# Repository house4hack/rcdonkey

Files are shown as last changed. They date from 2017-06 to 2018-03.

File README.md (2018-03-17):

RC Donkey
====

Based on the excellent project by Will Roscoe [https://github.com/wroscoe/donkey]

Simplified to use RC during training and driving - removing the need for WiFi and control using smartphone.

Talk from SatRDay included as a branch.

To automate running donkeyreader:

```
---------------------------------------------------

pi@raspberrypi:~ $ cat /etc/init.d/run_ai.sh
#!/bin/bash
### BEGIN INIT INFO
# Provides:          sample.py
# Required-Start:    $remote_fs $syslog
# Required-Stop:     $remote_fs $syslog
# Default-Start:     2 3 4 5
# Default-Stop:      0 1 6
# Short-Description: Start daemon at boot time
# Description:       Enable service provided by daemon.
### END INIT INFO

cd /home/pi/rcdonkey/donkeyreader/
./run.sh
pi@raspberrypi:~ $

pi@raspberrypi:~ $ sudo chmod +x /etc/init.d/run_ai.sh
pi@raspberrypi:~ $ sudo update-rc.d run_ai.sh defaults
pi@raspberrypi:~ $ sudo reboot

Done, once your Raspi booted up run.sh (donkeyreader) should already run in the background
---------------------------------------------------
```

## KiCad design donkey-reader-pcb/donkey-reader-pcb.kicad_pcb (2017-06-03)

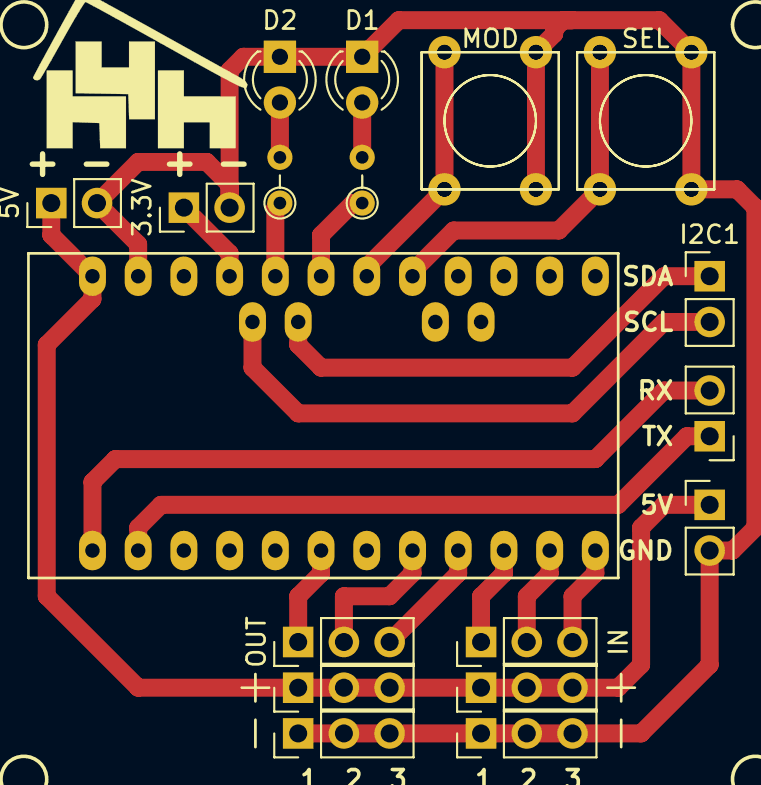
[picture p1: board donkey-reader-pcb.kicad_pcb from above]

Board: 2 copper layers, 20 parts (0 on the bottom side), 19 nets.

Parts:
3.3V, 5V: CONN_01X02; Pin_Header_Straight_1x02_Pitch2.54mm
+: CONN_01X03; Pin_Header_Straight_1x03_Pitch2.54mm
+#2: CONN_01X03; Pin_Header_Straight_1x03_Pitch2.54mm
-: CONN_01X03; Pin_Header_Straight_1x03_Pitch2.54mm
-#2: CONN_01X03; Pin_Header_Straight_1x03_Pitch2.54mm
D1, D2: LED; LED_D3.0mm
I2C1: CONN_01X02; Pin_Header_Straight_1x02_Pitch2.54mm
IC1: ArduinoProMini; pro_mini
IN: CONN_01X03; Pin_Header_Straight_1x03_Pitch2.54mm
MOD: SW_PUSH; SW_PUSH_SMALL
OUT: CONN_01X03; Pin_Header_Straight_1x03_Pitch2.54mm
PI: PI; Pin_Header_Straight_1x02_Pitch2.54mm
R1, R2: R; R_Axial_DIN0204_L3.6mm_D1.6mm_P2.54mm_Vertical
RX: CONN_01X02; Pin_Header_Straight_1x02_Pitch2.54mm
SEL: SW_PUSH; SW_PUSH_SMALL
SW1, SW2: SW_PUSH; SW_PUSH_SMALL

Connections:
+3V3: 3.3V.1, IC1.21
+5V: 5V.1, +.1, +.2, +.3, +#2.1, +#2.2, +#2.3, IC1.24, PI.1
GND: 3.3V.2, 5V.2, -.1, -.2, -.3, -#2.1, -#2.2, -#2.3, D1.1, D2.1, IC1.4, IC1.23, MOD.2, PI.2, SEL.2, SW1.2, SW2.2
LED1: IC1.19, R1.1
LED2: IC1.20, R2.1
unnamed: D1.2, R1.2
unnamed: D2.2, R2.2
unnamed: IC1.1, RX.2
unnamed: IC1.2, RX.1
unnamed: IC1.6, OUT.1
unnamed: IC1.8, OUT.2
unnamed: IC1.9, OUT.3
unnamed: IC1.10, IN.1
unnamed: IC1.11, IN.2
unnamed: IC1.12, IN.3
SCL: I2C1.2, IC1.26
SDA: I2C1.1, IC1.25
SW1: IC1.17, SEL.1, SW1.1
SW2: IC1.18, MOD.1, SW2.1

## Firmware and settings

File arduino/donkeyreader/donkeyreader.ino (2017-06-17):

#include <Servo.h> 
#define THROTTLE 7
#define TURN 8

#define THROTTLE_SERVO 3
#define TURN_SERVO 5

#define DRIVE_BUT 14
#define RECORD_BUT 15

#define DRIVE_LED 16
#define RECORD_LED 17

#define DEFAULT_ANGLE 1500
#define DEFAULT_THROTTLE 1500


#define CONTROL_SIZE 4
struct controlItem {
    int angle;              // 2
    int throttle;           // 2
};

union inputFromPC {
   controlItem controlData;
   byte pcLine[CONTROL_SIZE];
};

inputFromPC inputData;
byte pcData[CONTROL_SIZE];

#define EMPTY_DATA 1
#define MARKER1_DATA 2
#define MARKER2_DATA 3
#define RECV_DATA 4
#define NEW_DATA 5

char receiveState = EMPTY_DATA;
byte startMarker1 = 'A';
byte startMarker2 = 'A';
char recvIndex = 0;


#define RECORD_ON 1
#define RECORD_OFF 0
#define DRIVE_MANUAL 0
#define DRIVE_ANGLE 1
#define DRIVE_AUTO 2

#define CAR_OFF 0
#define CAR_ON 1
#define CAR_IDLE 2
#define CAR_STARTING 3
#define IDLE_TIME 60000
#define START_TIME 1000

//#define DEBUGPRINT Serial.print
#define DEBUGPRINT donothing

int record_mode= RECORD_OFF;
int drive_mode= DRIVE_MANUAL;
int car_state= CAR_STARTING;
int min_throttle = 1500;
long idle_start_time=0;
long starting_start_time = 0;
long last_blink=0;
char blink_on=0;

char throttle_passthru=true, turn_passthru=true;

Servo myservo_throttle, myservo_turn; 


#include <RunningMedian.h>

RunningMedian throttle_samples = RunningMedian(3);
RunningMedian turn_samples = RunningMedian(3);
 


int pwm_value_throttle=DEFAULT_THROTTLE, pwm_value_turn=DEFAULT_ANGLE;
void setup() {
  // put your setup code here, to run once:
  pinMode(THROTTLE, INPUT);
  pinMode(TURN, INPUT);
 
  pinMode(THROTTLE_SERVO, OUTPUT);
  pinMode(TURN_SERVO, OUTPUT);
  
  pinMode(RECORD_BUT, INPUT);
  digitalWrite(RECORD_BUT, HIGH);
  pinMode(DRIVE_BUT, INPUT);
  digitalWrite(DRIVE_BUT, HIGH);  
  
  pinMode(RECORD_LED, OUTPUT);
  pinMode(DRIVE_LED, OUTPUT);
  
  
  Serial.setTimeout(1000);
  Serial.begin(115200);
}
 
 
void display(){
  if(record_mode==RECORD_OFF){
    digitalWrite(RECORD_LED, LOW);
  } else if( record_mode == RECORD_ON){
    digitalWrite(RECORD_LED, HIGH);
  }
  
  if(drive_mode==DRIVE_MANUAL){
    digitalWrite(DRIVE_LED,LOW);
  } else if (drive_mode==DRIVE_ANGLE){
    digitalWrite(DRIVE_LED, HIGH); 
  } else if (drive_mode==DRIVE_AUTO){
    if(millis() - last_blink>100){
      blink_on = !blink_on;
      last_blink = millis();
    }
    digitalWrite(DRIVE_LED, blink_on);
  
  }
}




void readSerialData() { 
    byte rb;
   
    if(receiveState == NEW_DATA){
       return; 
    }
    
    if(receiveState == EMPTY_DATA){
       recvIndex = 0;
       if(Serial.available()){
          rb = Serial.read();
          if(rb == startMarker1){
             receiveState = MARKER1_DATA; 
             DEBUGPRINT("Marker1");
          }
       } 
    }
    //Serial.println(receiveState, DEC);    

    if(receiveState == MARKER1_DATA){
       if(Serial.available()){
          rb = Serial.read();
          if(rb == startMarker2){
             receiveState = RECV_DATA;
             DEBUGPRINT("Marker2");

 
          } else {
             receiveState = EMPTY_DATA; 
             DEBUGPRINT("Did not find marker2");
             DEBUGPRINT("Found:");
             DEBUGPRINT(rb,DEC);

          }
       } 
    }

    if(receiveState == RECV_DATA){
       while(Serial.available()){
          DEBUGPRINT("Receiving:");
          rb = Serial.read();
          DEBUGPRINT(rb,DEC);
          inputData.pcLine[recvIndex] = rb;
          recvIndex++;
          DEBUGPRINT("RecvIndex:");
          DEBUGPRINT(recvIndex, DEC);
          if(recvIndex == CONTROL_SIZE){
             receiveState = NEW_DATA;
             processSerialData();
             receiveState = EMPTY_DATA; 
             break; 
          }
       } 
    }
}


void processSerialData() {
  if(receiveState == NEW_DATA){
     /*for (byte n = 0; n < CONTROL_SIZE; n++) {
       inputData.pcLine[n] = pcData[n];
     }*/
     DEBUGPRINT("In process");
     pwm_value_throttle = inputData.controlData.throttle;
     pwm_value_turn     = inputData.controlData.angle;
     receiveState = EMPTY_DATA;
  }   
} 
 
void readFromPWM(){
   if(throttle_passthru ){
    pwm_value_throttle = pulseIn(THROTTLE, HIGH);
    
    if(pwm_value_throttle < 500){
       pwm_value_throttle = DEFAULT_THROTTLE;
       car_state = CAR_STARTING;
       starting_start_time = millis();
    } else if (car_state == CAR_STARTING && (millis() - starting_start_time > START_TIME)){
       min_throttle = pwm_value_throttle + 50;
       myservo_throttle.attach(THROTTLE_SERVO);
       myservo_turn.attach(TURN_SERVO);
       car_state = CAR_ON;
    } else if (pwm_value_throttle > min_throttle && car_state != CAR_ON) {
       myservo_throttle.attach(THROTTLE_SERVO);
       myservo_turn.attach(TURN_SERVO);
       car_state = CAR_ON;
    } else if (pwm_value_throttle < min_throttle  && car_state == CAR_ON) {
       car_state = CAR_IDLE;
       idle_start_time = millis(); 
    } else if (pwm_value_throttle < min_throttle && car_state == CAR_IDLE && (millis() - idle_start_time > IDLE_TIME)) {
       car_state = CAR_OFF;
       myservo_throttle.detach();
       myservo_turn.detach();
        
    }
    throttle_samples.add(pwm_value_throttle);
    pwm_value_throttle = throttle_samples.getMedian();   
  } 
  
  if(drive_mode == DRIVE_AUTO){
     int throttle = pulseIn(THROTTLE, HIGH);
     if(throttle < min_throttle){
        pwm_value_throttle  = throttle;  // prevent car run aways!
     }
  }

  if(turn_passthru){  
    pwm_value_turn = pulseIn(TURN, HIGH);
    if(pwm_value_turn < 500){
       pwm_value_turn = DEFAULT_ANGLE;
    }

    turn_samples.add(pwm_value_turn);  
    pwm_value_turn = turn_samples.getMedian();
     
  } 

} 

void readButtons(){
  if(!digitalRead(DRIVE_BUT)){
     if(drive_mode == DRIVE_MANUAL){
       drive_mode = DRIVE_ANGLE;
       turn_passthru = false;
       throttle_passthru = true;
     } else if (drive_mode == DRIVE_ANGLE) {
       drive_mode = DRIVE_AUTO;
       turn_passthru = false;
       throttle_passthru = false;

     } else if (drive_mode = DRIVE_AUTO){
       drive_mode = DRIVE_MANUAL;
       turn_passthru = true;
       throttle_passthru = true;
     } else {
       drive_mode = DRIVE_MANUAL;
       turn_passthru = true;
       throttle_passthru = true;
     }
     display();
     delay(500);
  }

  if(!digitalRead(RECORD_BUT)){
     if(record_mode == RECORD_OFF){
        record_mode = RECORD_ON; 
     } else if(record_mode== RECORD_ON){
        record_mode = RECORD_OFF;
     } else {
        record_mode= RECORD_OFF;
     }
     display();
     delay(500);
  } 
  
}


void donothing(String s){}
void donothing(String s, int arg){}
void donothing(byte b, int arg){}

void loop() {
  
  readSerialData(); 
  readFromPWM();
  readButtons();

  myservo_throttle.writeMicroseconds(pwm_value_throttle);
  myservo_turn.writeMicroseconds(pwm_value_turn); 

  
  Serial.print(pwm_value_throttle);
  Serial.print(",");
  Serial.print(pwm_value_turn);
  Serial.print(",");
  Serial.print(drive_mode);
  Serial.print(",");
  Serial.println(record_mode);
  
 
  display(); 
  
}

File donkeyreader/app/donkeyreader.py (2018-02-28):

import glob
import serial

import time
import struct
import traceback
import json
import modules.util as util
import os.path

import keras

#import donkey
#import donkey.utils
#import donkey.sensors

conf = json.load(open("config.json"))

import picamera
import modules.camera as cam
camera = cam.PiVideoStream()
camera.start()

l = glob.glob("/dev/ttyS0")
port = l[0]

is_recording= False
is_deciding=False
last_model_name=""
last_model_time=""
model = None
frame_no=0
while True:
    with serial.Serial(port, 115200, timeout=1) as ser:
        while ser.inWaiting():
            ser.readline()
        line = ser.readline()   # read a '\n' terminated line
        try:
            angle,throttle,dorecord,dodecide = util.decode_line(line,conf)
            print("From Arduino:",throttle,angle,frame_no, dorecord,dodecide)

            # Do we record? 
            if dorecord:
                # mount and create new folder to store images
                if not is_recording:
                    util.mount()
                    recording_folder = util.make_recording_folder(conf["save_folder"])
                    is_recording = True

                # get image from camera and save to disk
                frame = camera.capture_arr()
                filename = util.create_img_filepath(recording_folder,frame_no,angle, throttle, 0.0)
                print(filename)
                img = util.arr_to_img(frame)
                img.save(filename)
                frame_no+=1
            else:
                # unmount when we are done
                if is_recording:
                    is_recording = False                    
                    util.umount()

            # are we deciding?
            if dodecide:
                # load the pilot only if it has changed based on name and change date
                if not is_deciding:
                    util.mount()
                    last_model_name, last_model_time, model = util.check_and_load_model(conf["model_folder"], last_model_name, last_model_time, model)
                    if model != None:
                        is_deciding = True
                    if not is_recording:
                        util.umount()

                if is_deciding:
                    frame = camera.capture_arr()
                    angle,throttle = util.decide(model,frame/255.0)
                    angle_pwm,throttle_pwm= util.convertToPWM(angle, throttle,conf) 
                    print("To Arduino: %.2f: angle=%.2f throttle=%.2f angle_pwm=%d throttle_pwm=%d" % (time.time(), angle,throttle, angle_pwm, throttle_pwm))
                    util.sendToArduino(ser,angle_pwm,throttle_pwm)
            else:
                # finished deciding
                if is_deciding:
                    is_deciding = False

                time.sleep(0.1)
        except Exception as e:
            print(e)
            traceback.print_exc()

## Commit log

2017-06-10 Mode buttons
2017-06-10 mode buttons on python
2017-06-10 servo util and configfile
2017-06-13 arduino recordmode
2017-06-13 Added mount and umount functions to util.py Added mount and umount calls in donkeyreader.py This would make record button mount the USB flash drive Pressing the record button to stop the recording sh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
2017-06-13 Disable mode on arduino
2017-06-13 is_deciding mounting
2017-06-15 more robust mounting and unmounting
2017-06-15 removed opencv depency and using donkey camera
2017-06-17 Prevent car run-away in auto mode
    [donkeyreader.ino, donkeyreader.py]
2017-06-17 Fixed predicting of throttle
    [donkeyreader.py]
